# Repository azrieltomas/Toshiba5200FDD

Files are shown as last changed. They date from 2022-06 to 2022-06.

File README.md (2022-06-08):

# Toshiba 5200 FDD Adapter

This adapter converts the 26-way FDD IDC connector on the T5200 to a standard 34-way IDC connector. This way the old drive can be replaced with any 3.5" drive in case it fails (and by any, I mean any that only requires 5V).

(V1.0) Tested in:
* Toshiba T3200SX
* Toshiba T5200
	
Parts required:
* 26-way 2.54mm pitch IDC male header
* 34-way 2.54mm pitch IDC male header
* Corresponding 26-way and 34-way IDC cables
* 2-way header for jumper (& corresponding jumper pin)
* 4-pin Berg connector and two wires for the FDD power (you will need to solder this)


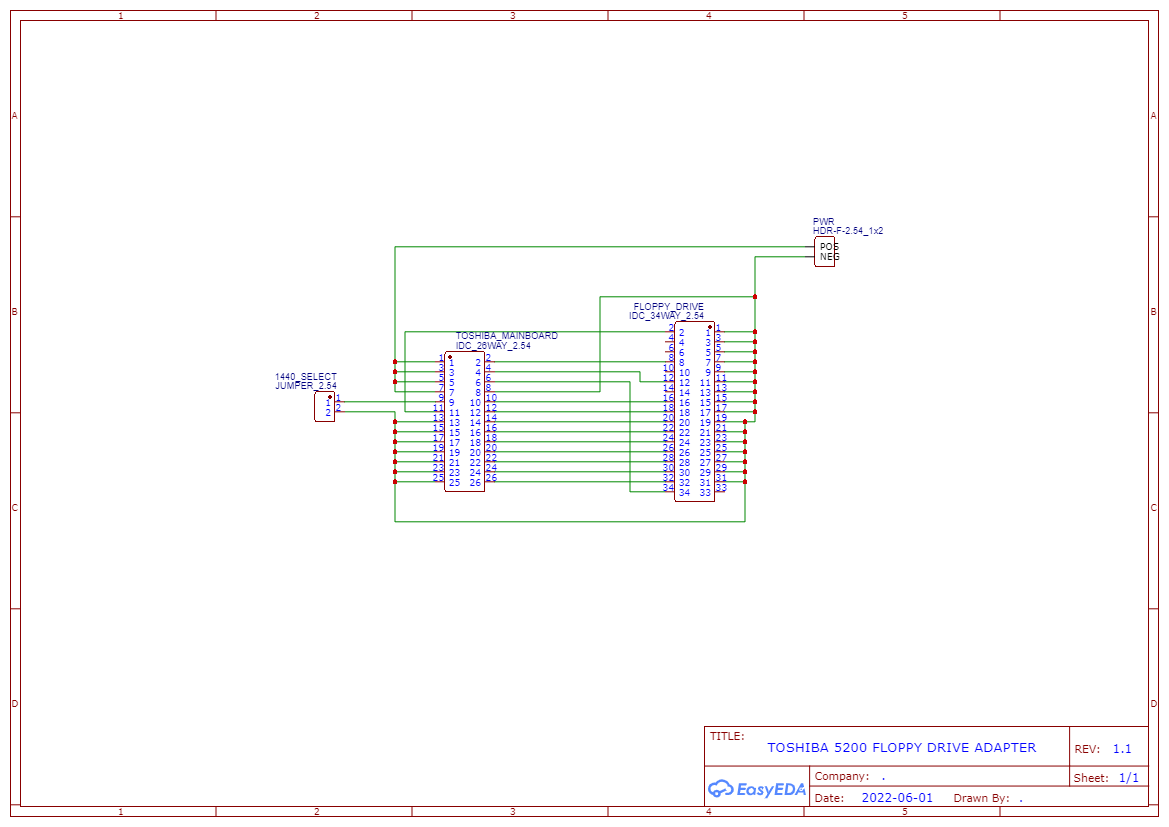
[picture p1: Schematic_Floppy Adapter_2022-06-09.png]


Due to limitations of the BIOS, the replacement drive can only format either 1.44MB or 720kB. This is defined by pin 9 on the 26-way (!NOTCH) connector. Inserting a jumper grounds this pin, setting it to 1.44MB, leaving it floating sets it to 720kB. Either way it will still read both kinds. Alternatively, you can format your floppies from DOS 3.3 or install a custom BIOS.

V1.0 of this PCB did not contain the !NOTCH jumper, instead it tied pin 9 permanently to ground.

This also ties !READY to ground, which may cause issues if you have more than one drive installed. See link below for more detail on this and a possible solution.

With thanks to IanB on the Vogons forum. See his posts here: https://www.vogons.org/viewtopic.php?f=46&t=57998

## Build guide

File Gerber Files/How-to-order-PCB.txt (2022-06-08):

How to Order PCB

Please refer to:
https://docs.easyeda.com/en/PCB/Order-PCB

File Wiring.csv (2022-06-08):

Toshiba Pin | Toshiba Signal | Drive Pin | Drive Signal
1 | 5V | - | (5V supply)
2 | !INDEX | 8 | !Index
3 | 5V | - | (5V supply)
4 | !FDSELA | 12 | !Drive select B
5 | 5V | - | (5V supply)
6 | !DSKCHG | 34 | !Disk change
7 | 5V | - | (5V supply)
8 | !READY | 5 | GND
9 | !NOTCH | - | GND
10 | !MONA | 16 | !Motor on B
11 | !LOWDNS | 2 | !High density
12 | !FDCDRC | 18 | !Direction
13 | GND | 19 | GND
14 | !STEP | 20 | !STEP
15 | GND | 21 | GND
16 | !WDATA | 22 | !Write data
17 | GND | 23 | GND
18 | !WGATE | 24 | !Write enable
19 | GND | 25 | GND
20 | !TRACK0 | 26 | !Track 0
21 | GND | 27 | GND
22 | !WPROTC | 28 | !Write protect
23 | GND | 29 | GND
24 | !RDDA | 30 | !Read data
25 | GND | 31 | GND
26 | !SIDE | 32 | !Side select
